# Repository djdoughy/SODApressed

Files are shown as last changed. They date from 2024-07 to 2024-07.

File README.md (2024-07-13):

# SODApressed
Percussive Enveloping Noise Generator



Features:

 -555 driven envelope

 -Triggerable by almost anything, at any length+

   -Attack cannot be retriggered until decay starts (this can make for some interesting half time hits if trigger is faster than attack time)

 -Transistor Noise generator

 -Beginner style DIY build

 -It's mostly analog!

Notes on building:
If you want a longer attack and decay, swap the capacitor on C5 from 4.7uF to 10uF (16V or larger)! Experiment! Have Fun!

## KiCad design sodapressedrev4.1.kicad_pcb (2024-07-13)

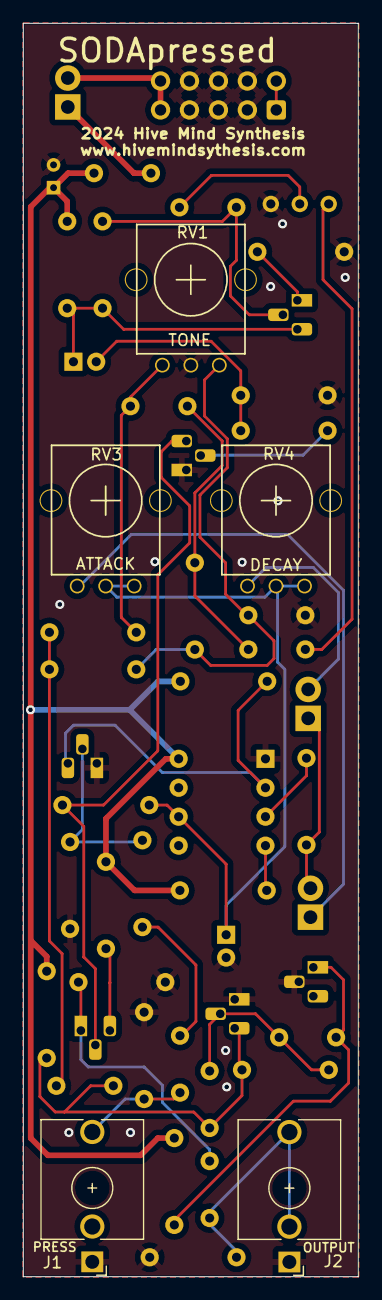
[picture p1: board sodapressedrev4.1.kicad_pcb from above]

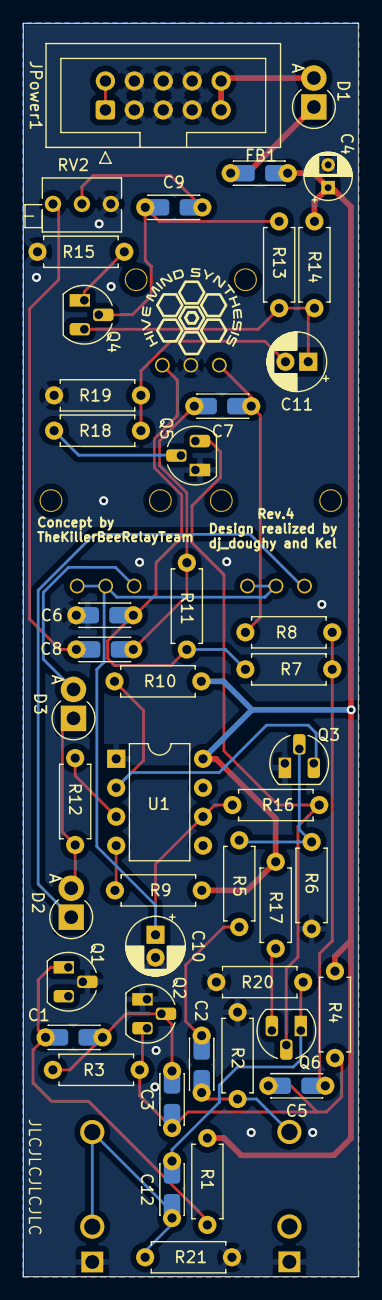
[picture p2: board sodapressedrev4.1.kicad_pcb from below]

Board: 2 copper layers, 29.4 x 110.0 mm, 51 parts (46 on the bottom side), 33 nets.

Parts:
C1: .1uF; C_Disc_P5.00mm_0805
C2: 1nF; C_Disc_P5.00mm_0805
C3: 10p; C_Disc_P5.00mm_0805
C4: 10u; CP_Radial_D4.0mm_P2.00mm
C5, C8: 1uF; C_Disc_P5.00mm_0805
C6, C7: 27nF; C_Disc_P5.00mm_0805
C9, C12: 10uF; C_Disc_P5.00mm_0805
C10: 4.7uF; CP_Radial_D5.0mm_P2.00mm
C11: 1uF; CP_Radial_D5.0mm_P2.00mm
D1: 1N5819; D_DO-15_P2.54mm_Vertical_AnodeUp
D2, D3: 1N4148; D_DO-15_P2.54mm_Vertical_AnodeUp
FB1: FerriteBead_Small; C_Disc_P5.00mm_0805
J1: PRESS; Jack_3.5mm_QingPu_WQP-PJ398SM_Vertical_CircularHoles
J2: Output; Jack_3.5mm_QingPu_WQP-PJ398SM_Vertical_CircularHoles
JPower1: EurorackPower; IDC-Header_2x05_P2.54mm_Vertical
Q1, Q2, Q3, Q4, Q5, Q6: 2N3904; TO-92_HandSolder
R1: 200k; R_Axial_DIN0207_L6.3mm_D2.5mm_P7.62mm_Horizontal
R2, R5, R10: 10k; R_Axial_DIN0207_L6.3mm_D2.5mm_P7.62mm_Horizontal
R3: 2M2; R_Axial_DIN0207_L6.3mm_D2.5mm_P7.62mm_Horizontal
R4, R7, R8, R11, R19, R20, R21: 4k7; R_Axial_DIN0207_L6.3mm_D2.5mm_P7.62mm_Horizontal
R6, R9, R18: 100k; R_Axial_DIN0207_L6.3mm_D2.5mm_P7.62mm_Horizontal
R12: 1k; R_Axial_DIN0207_L6.3mm_D2.5mm_P7.62mm_Horizontal
R13: 1M; R_Axial_DIN0207_L6.3mm_D2.5mm_P7.62mm_Horizontal
R14: 2.2k; R_Axial_DIN0207_L6.3mm_D2.5mm_P7.62mm_Horizontal
R15: 150; R_Axial_DIN0207_L6.3mm_D2.5mm_P7.62mm_Horizontal
R16: 110k; R_Axial_DIN0207_L6.3mm_D2.5mm_P7.62mm_Horizontal
R17: 100; R_Axial_DIN0207_L6.3mm_D2.5mm_P7.62mm_Horizontal
RV1: 10k; Alpha9mmPot
RV2: 100k; Potentiometer_Bourns_3266Z_Horizontal
RV3, RV4: 50k; Alpha9mmPot
U1: ICM7555xP; DIP-8_W7.62mm

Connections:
+12V: C4.1, FB1.2, R1.1, R4.1, R9.1, R10.1, R14.2, R17.2, U1.8 (VCC)
GND: C4.2, C6.2, C10.2, J1.S (Sleeve), J2.S (Sleeve), JPower1.3 (GND), JPower1.4 (GND), JPower1.5 (GND), JPower1.6 (GND), JPower1.7 (GND), JPower1.8 (GND), Q1.2 (B), Q2.1 (E), Q3.1 (E), Q5.1 (E), R2.2, R6.2, R15.1, R19.1, R20.1, R21.1, RV1.2, RV2.1, U1.1 (GND)
unnamed: C2.1, R5.1
unnamed: C5.1, R7.1, R8.2
unnamed: C6.1, R7.2, R11.1, RV1.3
unnamed: C7.1, R8.1, RV1.1
unnamed: C7.2, C8.2, R11.2
unnamed: C8.1, RV2.3
unnamed: C9.2, RV2.2
unnamed: C11.2, R18.2, R19.2
unnamed: D1.2 (A), JPower1.9 (+12V), JPower1.10 (+12V)
unnamed: D1.1 (K), FB1.1
unnamed: D2.2 (A), D3.1 (K), R12.2
unnamed: D2.1 (K), RV3.1
unnamed: D3.2 (A), RV4.1
unnamed: C2.2, J1.T (Tip), R2.1
unnamed: C12.1, J2.T (Tip), J2.TN (Tip_normalize), R21.2
unnamed: JPower1.1 (-12V), JPower1.2 (-12V)
unnamed: C1.2, Q1.1 (E), R1.2
unnamed: C1.1, C3.2, Q2.2 (B), R3.1
unnamed: C3.1, C5.2, Q2.3 (C), R3.2, R4.2
unnamed: Q3.2 (B), R5.2, R6.1
unnamed: Q3.3 (C), R10.2, U1.2 (TR)
unnamed: C9.1, Q4.2 (B), R13.1
unnamed: C11.1, Q4.3 (C), R13.2, R14.1
unnamed: Q4.1 (E), R15.2
unnamed: Q5.2 (B), R18.1
unnamed: Q5.3 (C), Q6.2 (B), R16.1
unnamed: Q6.3 (C), R17.1
unnamed: C12.2, Q6.1 (E), R20.2
unnamed: R12.1, U1.3 (Q)
unnamed: R9.2, U1.4 (R)
unnamed: C10.1, R16.2, RV3.2, RV3.3, RV4.2, RV4.3, U1.6 (THR)

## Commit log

2024-07-13 Init Project Upload
    [sodapressedrev4.1.kicad_pcb, sodapressedrev4.1.kicad_sch]
2024-07-13 Panel init
    [sodapressedrev4.1-colorpanel.kicad_pcb, sodapressedrev4.1-panel.kicad_pcb]
2024-07-16 Mouser BOM
    Importable mouser bom.
    [SodaPressed - MouserBom.xls]
2024-07-16 Delete SodaPressed - MouserBom.xls
    Wrong parts
    [SodaPressed - MouserBom.xls]
